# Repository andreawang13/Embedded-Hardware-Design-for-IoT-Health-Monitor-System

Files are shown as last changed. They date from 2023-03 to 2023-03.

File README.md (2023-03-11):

# PCB layout design
截屏2023-03-11 11 43 37
截屏2023-03-11 11 43 57
截屏2023-03-11 11 44 27

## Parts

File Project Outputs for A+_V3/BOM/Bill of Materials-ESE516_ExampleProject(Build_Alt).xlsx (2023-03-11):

Line # | Name | Description | Designator | Quantity | Manufacturer 1 | Manufacturer Part Number 1 | Manufacturer Lifecycle 1 | Supplier 1 | Supplier Part Number 1 | Supplier Unit Price 1 | Supplier Subtotal 1 | Actuator Color | Actuator Length | Actuator Travel | Actuator Type | Address1 | Address2 | Address3 | Address4 | Agency Approvals | Angle | Application_BuildNumber | Arrow Part Number | ApprovedBy | Arrow Price/Stock | Author | Automotive | Availability | Battery Chemistry | Battery Pack Voltage | Body Breadth | Body Depth | Body Length | Body/Shell Style | BOM Status Details | Brand | Brand/Series | Capacitance | BOM Status | Capacitance Value | Capacitor Type | Card Type | Case Code (Imperial) | Case Code (Metric) | Case/Package | Category | Category2 | Check_prices | CheckedBy | Circuit | Code_IPC | Color | CompanyName | Component Kind | ComponentKind | ComponentLink1Description | ComponentLink1URL | ComponentLink2Description | ComponentLink2URL
1 | PTS810SJK250SMTRLFS | Keypad Switch, 1 Switches, SPST, Momentary-tactile, 0.05A, 16VDC, 3.23N, Solder Terminal, Surface Mount-straight | B1, B3, B4 | 3 | Grayhill | 87FC3-201 | Volume Production | Digi-Key | GH7750-ND | 16.55 | 49.65 | White | 0.028inch | 0.1524mm | Pushbutton |  |  |  |  |  |  |  |  |  |  |  |  |  |  |  |  |  |  |  |  |  |  |  | Clear |  |  |  |  |  |  |  |  |  |  | SPST |  |  |  | Standard | 0
2 | CAP 0603 0.01UF 16V 10% X7R | Capacitor Surface Mount 0603 Footprint 0.01UF 16V 10% Tolerance Ceramic X7R | C1 | 1 | Yageo | CC0603KRX7R7BB103 | Volume Production | Digi-Key | 311-3369-1-ND | 0.1 | 0.1 |  |  |  |  |  |  |  |  |  |  |  |  |  |  |  |  |  |  |  |  |  |  |  |  |  |  |  | Clear |  |  |  |  |  |  |  |  |  |  |  |  |  |  | Standard | 0
3 | CAP 0603 0.1UF 16V 10% X7R | Capacitor Surface Mount 0603 Footprint 0.1UF 16V 10% Tolerance Ceramic X7R | C2, C6, C7, C15, C30 | 5 | Yageo | CC0603KRX7R7BB104 | Volume Production | Digi-Key | 311-1088-1-ND | 0.044 | 0.44 |  |  |  |  |  |  |  |  |  |  |  |  |  |  |  |  |  |  |  |  |  |  |  |  |  |  |  | Clear |  |  |  |  |  |  |  |  |  |  |  |  |  |  | Standard | 0
4 | CAP 0805 4.7UF 16V 10% X7R | Capacitor Surface Mount 0805 Footprint 4.7UF 16V 10% Tolerance Ceramic X7R | C3, C25, C26 | 3 | Yageo | CC0805KKX7R7BB475 | Volume Production | Digi-Key | 311-1883-1-ND | 0.39 | 1.17 |  |  |  |  |  |  |  |  |  |  |  |  |  |  |  |  |  |  |  |  |  |  |  |  |  |  |  | Clear |  |  |  |  |  |  |  |  |  |  |  |  |  |  | Standard | 0
5 | CAP 0603 47PF 50V 5% C0G | Capacitor Surface Mount 0603 Footprint 47PF 50V 5% Tolerance Ceramic C0G | C4, C5 | 2 | Yageo | 223886715479 | Volume Production | Quest | 223886715479 | 0.06 | 0.12 |  |  |  |  |  |  |  |  |  |  |  |  |  |  |  |  |  |  |  |  |  |  |  |  |  |  |  | Clear |  |  |  |  |  |  |  |  |  |  |  |  |  |  | Standard | 0
6 | CAP 0603 1UF 16V 10% X7R | Capacitor Surface Mount 0603 Footprint 1UF 16V 10% Tolerance Ceramic X7R | C8, C9, C12, C19, C20, C24 | 6 | Yageo | CC0603KRX7R7BB105 | Volume Production | Digi-Key | 311-1446-1-ND | 0.14 | 0.84 |  |  |  |  |  |  |  |  |  |  |  |  |  |  |  |  |  |  |  |  |  |  |  |  |  |  |  | Clear |  |  |  |  |  |  |  |  |  |  |  |  |  |  | Standard | 0
7 | CAP 0805 10UF 16V 20% X7R | Capacitor Surface Mount 0805 Footprint 10UF 16V 20% Tolerance Ceramic X7R | C10, C11, C18, C29, C31 | 5 | Yageo | CC1210KFX7R8BB106 | Unknown | Digi-Key | 13-CC1210KFX7R8BB106CT-ND | 0.53 | 2.65 |  |  |  |  |  |  |  |  |  |  |  |  |  |  |  |  |  |  |  |  |  |  |  |  |  |  |  | Clear |  |  |  |  |  |  |  |  |  |  |  |  |  |  | Standard | 0
8 | CAP 0603 18PF 50V 5% C0G | Capacitor Surface Mount 0603 Footprint 18PF 50V 5% Tolerance Ceramic C0G | C13, C14 | 2 | Yageo | CC0603JRNPO9BN180 | Volume Production | Digi-Key | 311-1061-1-ND | 0.1 | 0.2 |  |  |  |  |  |  |  |  |  |  |  |  |  |  |  |  |  |  |  |  |  |  |  |  |  |  |  | Clear |  |  |  |  |  |  |  |  |  |  |  |  |  |  | Standard | 0
9 | CC0805KPX7R9BB104 | CC0805 100 nF X7R 10.00% 50 V | C16, C17, C22, C27 | 4 | Yageo | CC0805KPX7R9BB104 | Volume Production | Digi-Key | 13-CC0805KPX7R9BB104CT-ND | 0.1 | 0.4 |  |  |  |  |  |  |  |  |  |  |  |  |  |  |  | No |  |  |  |  |  |  |  |  |  |  | 100 nF | Clear |  |  |  |  |  |  | Cap |  |  |  |  |  |  |  | Standard | 0 |  |  | Datasheet | http://www.yageo.com/documents/recent/UPY-GPHC_Y5V_6.3V-to-50V_8.pdf
10 | CAP 1206 10UF 50V 10% X5R | Capacitor Surface Mount 1206 Footprint 10UF 25V 10% Tolerance Ceramic X5R | C21 | 1 | Yageo | CC1210KFX7R8BB106 | Unknown | Digi-Key | 13-CC1210KFX7R8BB106CT-ND | 0.53 | 0.53 |  |  |  |  |  |  |  |  |  |  |  |  |  |  |  |  |  |  |  |  |  |  |  |  |  |  |  | Clear |  | Ceramic |  |  |  | 1206 |  |  |  |  |  |  |  |  | Standard | 0
11 | CC0805MKX7R8BB475 | CAP CER 4.7UF 25V X7R 0805 | C23 | 1 | Yageo | CC0805MKX7R8BB475 | Volume Production | Digi-Key | 311-3509-1-ND | 0.39 | 0.39 |  |  |  |  |  |  |  |  |  |  |  |  |  |  |  | No |  |  |  |  |  |  |  |  |  |  | 4.7 uF | Clear |  |  |  |  |  |  | Cap |  |  |  |  |  |  |  | Standard | 0 |  |  | Datasheet | http://www.yageo.com/documents/recent/UPY-GPHC_Y5V_6.3V-to-50V_8.pdf
12 | CAP 1206 22UF 10V 10% X7R | Capacitor Surface Mount 1206 Footprint 22UF 10V 10% Tolerance Ceramic X7R | C28 | 1 | Yageo | CC1210MKX7R7BB226 | Volume Production | Digi-Key | 311-2057-1-ND | 0.68 | 0.68 |  |  |  |  |  |  |  |  |  |  |  |  |  |  |  |  |  |  |  |  |  |  |  |  |  |  |  | Clear |  | Ceramic |  |  |  | 1206 |  |  |  |  |  |  |  |  | Standard | 0
13 | LSM0805412V | Single Color LED, RED, 0805 | D1, D3, D11 | 3 | Visual Communications | LSM0805412V | Volume Production | Digi-Key | 28-LSM0805412VDKR-ND | 0.47 | 1.41 |  |  |  |  |  |  |  |  |  |  |  |  |  |  |  |  |  |  |  |  |  |  |  |  |  |  |  | Clear |  |  |  |  |  |  |  |  |  |  |  |  |  |  | Standard | 0
14 | PRTR5V0U2X,215 | Ultra Low Capacitance Double Rail-to-Rail ESD Protection Diode, 5.5 V, 1 pF, -40 to 85 degC, 4-Pin SOT143B, RoHS, Tape and Reel | D2 | 1 | Nexperia | PRTR5V0U2X,215 | Volume Production | Digi-Key | 1727-3884-1-ND | 0.51 | 0.51 |  |  |  |  |  |  |  |  |  |  |  |  |  |  |  |  |  |  |  |  |  |  |  |  |  |  |  | Clear | 16pF |  |  |  |  |  |  |  |  |  |  |  |  |  | Standard | 0
15 | LSM0805452V | Single Color LED, Green, 0805 | D4, D8, D9, D10 | 4 | Visual Communications | LSM0805452V | Volume Production | Digi-Key | 28-LSM0805452VCT-ND | 0.41 | 1.64 |  |  |  |  |  |  |  |  |  |  |  |  |  |  |  |  |  |  |  |  |  |  |  |  |  |  |  | Clear |  |  |  |  |  |  |  |  |  |  |  |  |  |  | Standard | 0
16 | BLM21PG221SN1D | Chip Ferrite Bead, 0805, 220Ω @ 100MHz, 0.045Ω, 25%, 2A | FB1 | 1 | Murata | BLM21PG221SN1D | Unknown | Digi-Key | 490-1054-1-ND | 0.12 | 0.12 |  |  |  |  |  |  |  |  |  |  |  |  |  |  |  |  |  |  |  |  |  |  |  |  |  |  |  | Clear |  |  |  | 0805 | 2012 | 0805 |  |  |  |  |  |  |  |  | Standard | 0
17 | LTC1503CS8-1.8 | Integrated Circuit | IC1 | 1 | Analog Devices / Linear Technology | LTC1503CS8-1.8#PBF | Volume Production | Digi-Key | LTC1503CS8-1.8#PBF-ND | 6.07 | 6.07 |  |  |  |  |  |  |  |  |  |  |  |  |  |  |  |  |  |  |  |  |  |  |  |  |  |  |  | Clear |  |  |  |  |  |  |  |  |  |  |  |  |  |  | Standard | 0
18 | 10103592-0001LF | Conn Micro USB 2.0 Type B RCP 5 POS 0.65mm Solder RA SMD 5 Terminal 1 Port T/R | J1 | 1 | Amphenol Communications Solutions | 10103592-0001LF | Unknown | Digi-Key | 609-4048-1-ND | 0.8 | 0.8 |  |  |  |  |  |  |  |  |  |  |  |  |  |  |  |  |  |  |  |  |  |  |  |  |  |  |  | Clear |  |  |  |  |  |  |  |  |  |  |  |  |  |  | Standard | 0
19 | PAM2401 | Conv DC-DC 0.9V to 4.75V Synchronous Step Up Single-Out 2.5V to 5V 12-Pin UDFN EP T/R | J2 | 1 | Diodes | PAM2401SCADJ | Volume Production | Digi-Key | PAM2401SCADJDITR-ND | 0.45 | 1125 |  |  |  |  |  |  |  |  |  |  |  |  |  |  |  |  | In Stock |  |  |  |  |  |  |  |  |  |  | Clear |  |  |  |  |  |  |  |  | https://www.snapeda.com/parts/PAM2401/Zetex/view-part/?ref=eda |  |  |  |  |  | Standard | 0
20 | 2.2uH | IND 2.2uH 0.22A 280mâ„| | L1 | 1 | Murata | LQM21PN2R2NGCD | Volume Production | Digi-Key | 490-7781-6-ND | 0.23 | 0.23 |  |  |  |  |  |  |  |  |  |  |  |  |  |  |  |  | In Stock |  |  |  |  |  |  |  |  |  |  | Clear |  |  |  |  |  |  |  |  | https://www.snapeda.com/parts/ASMCI-0805-2R2M-T/Abracon/view-part/?ref=eda |  |  |  |  |  | Standard | 0
21 | 640456-3 | CONN HEADER VERT 3POS 2.54MM | P1, P2 | 2 | TE Connectivity | 640456-2 | Volume Production | Digi-Key | A1921-ND | 0.14 | 0.28 |  |  |  |  |  |  |  |  | CSA,UL | Straight |  |  |  |  |  |  |  |  |  |  |  |  |  |  |  | MTA-100Series |  | Clear |  |  |  |  |  |  |  |  |  |  |  |  | White |  | Standard | 0
22 | BSS138 | N-CH MOSFET 50V 0.34A SOT-23-3L | Q1, Q2 | 2 | Diodes | BSS138W-7-F | Volume Production | Digi-Key | BSS138W-FDIDKR-ND | 0.31 | 0.62 |  |  |  |  |  |  |  |  |  |  |  |  |  |  |  |  | In Stock |  |  |  |  |  |  |  |  |  |  | Clear |  |  |  |  |  |  |  |  | https://www.snapeda.com/parts/BSS138/Diodes+Inc./view-part/?ref=eda |  |  |  |  |  | Standard | 0
23 | RES 0603 27 1% | Resistor Surface Mount, 27 Ohms, 0603 Footprint, 1% Tolerance 0.1W | R1, R2, R8, R9, R10 | 5 | Stackpole Electronics | RMCF0402FT27R0 | Volume Production | Digi-Key | RMCF0402FT27R0CT-ND | 0.014 | 0.14 |  |  |  |  |  |  |  |  |  |  |  |  |  |  |  |  |  |  |  |  |  |  |  |  |  |  |  | Clear |  |  |  |  |  |  |  |  |  |  |  |  |  |  | Standard | 0
24 | RES 0603 1K 1% | Resistor Surface Mount, 1K Ohms, 0603 Footprint, 1% Tolerance 0.1W | R3, R5, R6, R7, R18, R19, R37, R38 | 8 | Yageo | RC0603FR-071KL | Unknown | Digi-Key | 311-1.00KHRDKR-ND | 0.019 | 0.19 |  |  |  |  |  |  |  |  |  |  |  |  |  |  |  |  |  |  |  |  |  |  |  |  |  |  |  | Clear |  |  |  |  |  |  |  |  |  |  |  |  |  |  | Standard | 0
25 | RES 0805 0 5% | Resistor Surface Mount, 0 Ohms, 0805 Footprint, 5% Tolerance 0.125W | R4, R16, R23, R24, R27, R35, R39, R41, R42, R45, R47, R48, R49, R50, R51, R? | 16 | Rohm | KTR10EZPJ205 | Volume Production | Digi-Key | RHM2.0MBCT-ND | 0.143 | 2.29 |  |  |  |  |  |  |  |  |  |  |  |  |  |  |  |  |  |  |  |  |  |  |  |  |  |  |  | Clear |  |  |  |  |  |  |  |  |  |  |  |  |  |  | Standard | 0
26 | RES 0603 10K 1% | Resistor Surface Mount, 10K Ohms, 0603 Footprint, 1% Tolerance 0.1W | R11, R13, R14, R15, R30, R31, R32, R52, R53 | 9 | Stackpole Electronics | RMCF0603FT10K0 | Volume Production | Digi-Key | RMCF0603FT10K0DKR-ND | 0.016 | 0.16 |  |  |  |  |  |  |  |  |  |  |  |  |  |  |  |  |  |  |  |  |  |  |  |  |  |  |  | Clear |  |  |  |  |  |  |  |  |  |  |  |  |  |  | Standard | 0
27 | RES 0603 100 1% | Resistor Surface Mount, 100 Ohms, 0603 Footprint, 1% Tolerance 0.1W | R12 | 1 | Stackpole Electronics | RMCF0402FT100R | Volume Production | Digi-Key | RMCF0402FT100RCT-ND | 0.1 | 0.1 |  |  |  |  |  |  |  |  |  |  |  |  |  |  |  |  |  |  |  |  |  |  |  |  |  |  |  | Clear |  |  |  |  |  |  |  |  |  |  |  |  |  |  | Standard | 0
28 | RES 0402 4.7K 1% | Resistor Surface Mount, 4.7K Ohms, 0402 Footprint, 1% Tolerance 0.063W | R17, R22, R28, R29, R33, R34, R40 | 7 | Stackpole Electronics | RMCF0402FT4K70 | Volume Production | Digi-Key | RMCF0402FT4K70DKR-ND | 0.014 | 0.14 |  |  |  |  |  |  |  |  |  |  |  |  |  |  |  |  |  |  |  |  |  |  |  |  |  |  |  | Clear |  |  |  |  |  |  |  |  |  |  |  |  |  |  | Standard | 0
29 | RES 0603 1.13K 1% | Resistor Surface Mount, 1.13K Ohms, 0603 Footprint, 1% Tolerance 0.1W | R20, R21 | 2 | Stackpole Electronics | RMCF0402FT1K13 | Volume Production | Digi-Key | RMCF0402FT1K13CT-ND | 0.014 | 0.14 |  |  |  |  |  |  |  |  |  |  |  |  |  |  |  |  |  |  |  |  |  |  |  |  |  |  |  | Clear |  |  |  |  |  |  |  |  |  |  |  |  |  |  | Standard | 0
30 | RES 0402 750K 5% | Resistor Surface Mount, 750K Ohms, 0402 Footprint, 5% Tolerance 0.063W | R25 | 1 | Stackpole Electronics | RMCF0402FT750K | Volume Production | Digi-Key | RMCF0402FT750KCT-ND | 0.1 | 0.1 |  |  |  |  |  |  |  |  |  |  |  |  |  |  |  |  |  |  |  |  |  |  |  |  |  |  |  | Clear |  |  |  |  |  |  |  |  |  |  |  |  |  |  | Standard | 0
31 | RES 0603 100K 5% | Resistor Surface Mount, 100K Ohms, 0603 Footprint, 5% Tolerance 0.1W | R26, R36 | 2 | Stackpole Electronics | RMCF0603JG100K | Volume Production | Digi-Key | RMCF0603JG100KCT-ND | 0.014 | 0.14 |  |  |  |  |  |  |  |  |  |  |  |  |  |  |  |  |  |  |  |  |  |  |  |  |  |  |  | Clear |  |  |  |  |  |  |  |  |  |  |  |  |  |  | Standard | 0
32 | 104031-0811 | Micro SD Card, RA, -25 to 85 degC, 8-Pin SMD, RoHS, Tape and Reel | SD1 | 1 | Molex | 1040310811 | Unknown | Digi-Key | WM6357DKR-ND | 2.24 | 2.24 |  |  |  |  |  |  |  |  |  |  |  |  |  |  |  |  |  |  |  |  |  |  |  |  | Molex |  |  | Clear |  |  | microSD |  |  |  |  |  |  |  |  |  |  |  | Standard | 0
33 | FT234XD-R | IC USB SERIAL BASIC UART 12DFN | U1 | 1 | FTDI | FT234XD-R | Volume Production | Digi-Key | 768-1178-1-ND | 2.26 | 2.26 |  |  |  |  |  |  |  |  |  |  |  |  |  |  |  |  |  |  |  |  |  |  |  |  |  |  |  | Clear |  |  |  |  |  | DFN |  |  |  |  |  |  |  |  | Standard | 0
34 | MCP1824T-3302E/OT | 300 mA, Low Voltage, Low Quiescent Current LDO Regulator, 5-Pin SOT-23, Extended Temperature, Tape and Reel | U2 | 1 | Microchip | MCP1824T-3302E/OT | Volume Production | Digi-Key | MCP1824T-3302E/OTCT-ND | 0.59 | 0.59 |  |  |  |  |  |  |  |  |  |  |  |  |  |  |  |  |  |  |  |  |  |  |  |  |  |  |  | Clear |  |  |  |  |  |  |  |  |  |  |  | SOT23-5 |  |  | Standard | 0
35 | 20021111-00010T4LF | Board Connector, 10 Contact(s), 2 Row(s), Male, Straight, 0.05 inch Pitch, Solder Terminal, Locking, Black Insulator, Receptacle | U3 | 1 | Amphenol ICC / FCI | 20021111-00010T4LF | Unknown | Mouser | 649-221111-00010T4LF | 0.79 | 0.79 |  |  |  |  |  |  |  |  |  |  |  |  |  |  |  |  |  |  |  | 0.135inch | 0.098inch | 0.25inch | RECEPTACLE |  |  |  |  | Clear |  |  |  |  |  |  |  |  |  |  |  |  |  |  | Standard | 0
36 | ATSAMW25H18-MR210PB | 2.7 - 4.2 V 65 Mbps 17 dbm 256 kB Flash 32 kB SRAM 802.11 b/g/n Smart Module | U4 | 1 | Microchip | ATSAMW25H18-MR210PB1954 | Volume Production | microchipDIRECT | ATSAMW25H18-MR210PB1954 | 15.15 | 15.15 |  |  |  |  |  |  |  |  |  |  |  |  |  |  |  |  |  |  |  |  |  |  |  |  |  |  |  | Clear |  |  |  |  |  |  |  |  |  |  |  |  |  |  | Standard | 0
37 | BQ24075RGTR | IC LI-ION CHARGE MGMT 16-QFN | U6 | 1 | Texas Instruments | BQ24075RGTR | Volume Production | Digi-Key | 296-38874-1-ND | 2.53 | 2.53 |  |  |  |  |  |  |  |  |  |  |  |  |  |  |  |  |  | LITHIUM-ION | 4.2V |  |  |  |  |  |  |  |  | Clear |  |  |  |  |  | VQFN |  |  |  |  |  |  |  |  | Standard | 0
38 | MAX30101EFD+ | Oximeter/Heart Rate Sensor IÂ²C Output | U7 | 1 | Maxim | MAX30101EFD+ | Volume Production | One Stop Electro | 55433695 | 1.65 | 1.65 |  |  |  |  |  |  |  |  |  |  |  |  |  |  |  |  | Unavailable |  |  |  |  |  |  |  |  |  |  | Clear |  |  |  |  |  |  |  |  |  |  |  |  |  |  | Standard | 0
39 | BME680 | Gas, Humidity, Pressure, Temperature Sensor IÂ²C, SPI Output | U9 | 1 | Bosch Sensortec | BME680 | Unknown | LKR | 9004993 | 8.69 | 8.69 |  |  |  |  |  |  |  |  |  |  |  |  |  |  |  |  | In Stock |  |  |  |  |  |  |  |  |  |  | Clear |  |  |  |  |  |  |  |  | https://www.snapeda.com/parts/BME680/Bosch+Sensortec/view-part/?ref=eda |  |  |  |  |  | Standard | 0
40 | ABS07-32.768KHZ-T | Crystal 32.768kHz ±20ppm (Tol) 12.5pF FUND 70kΩ 2-Pin CSMD T/R | X1 | 1 | Abracon | ABS07-32.768KHZ-T | Volume Production | Digi-Key | 535-9542-1-ND | 0.72 | 0.72 |  |  |  |  |  |  |  |  |  |  |  |  |  |  |  |  |  |  |  |  |  |  |  |  |  |  |  | Clear |  |  |  |  |  | CSMD |  |  |  |  |  |  |  |  | Standard | 0
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

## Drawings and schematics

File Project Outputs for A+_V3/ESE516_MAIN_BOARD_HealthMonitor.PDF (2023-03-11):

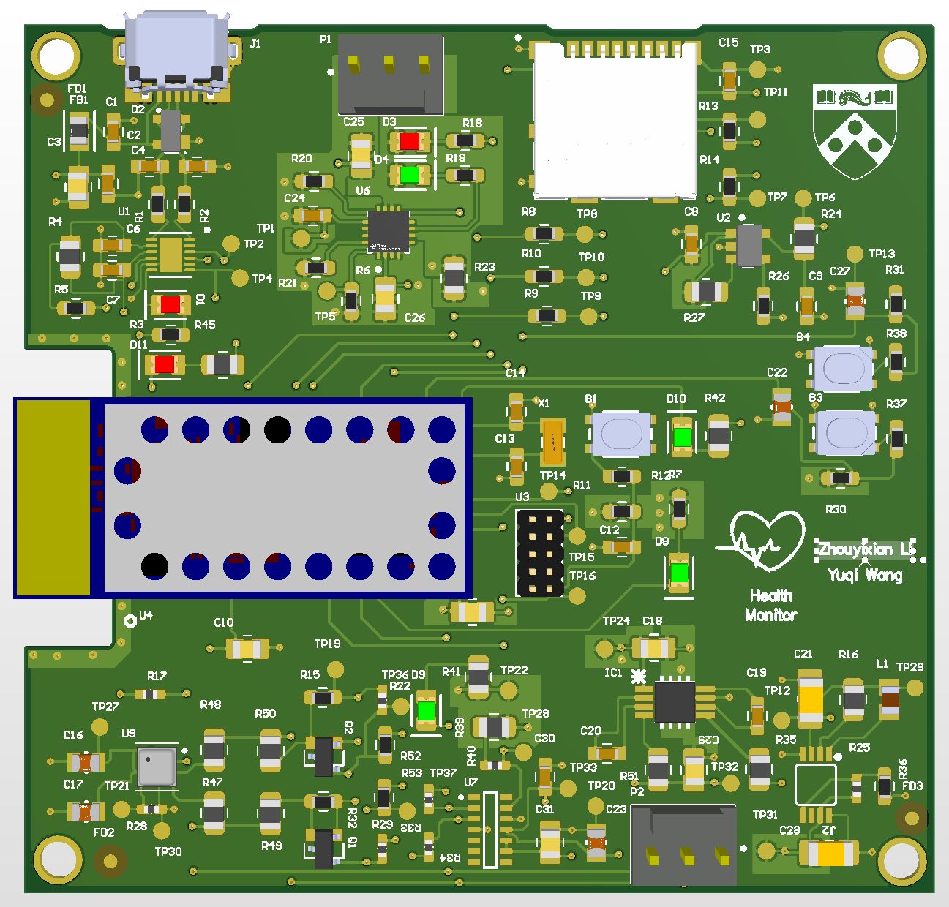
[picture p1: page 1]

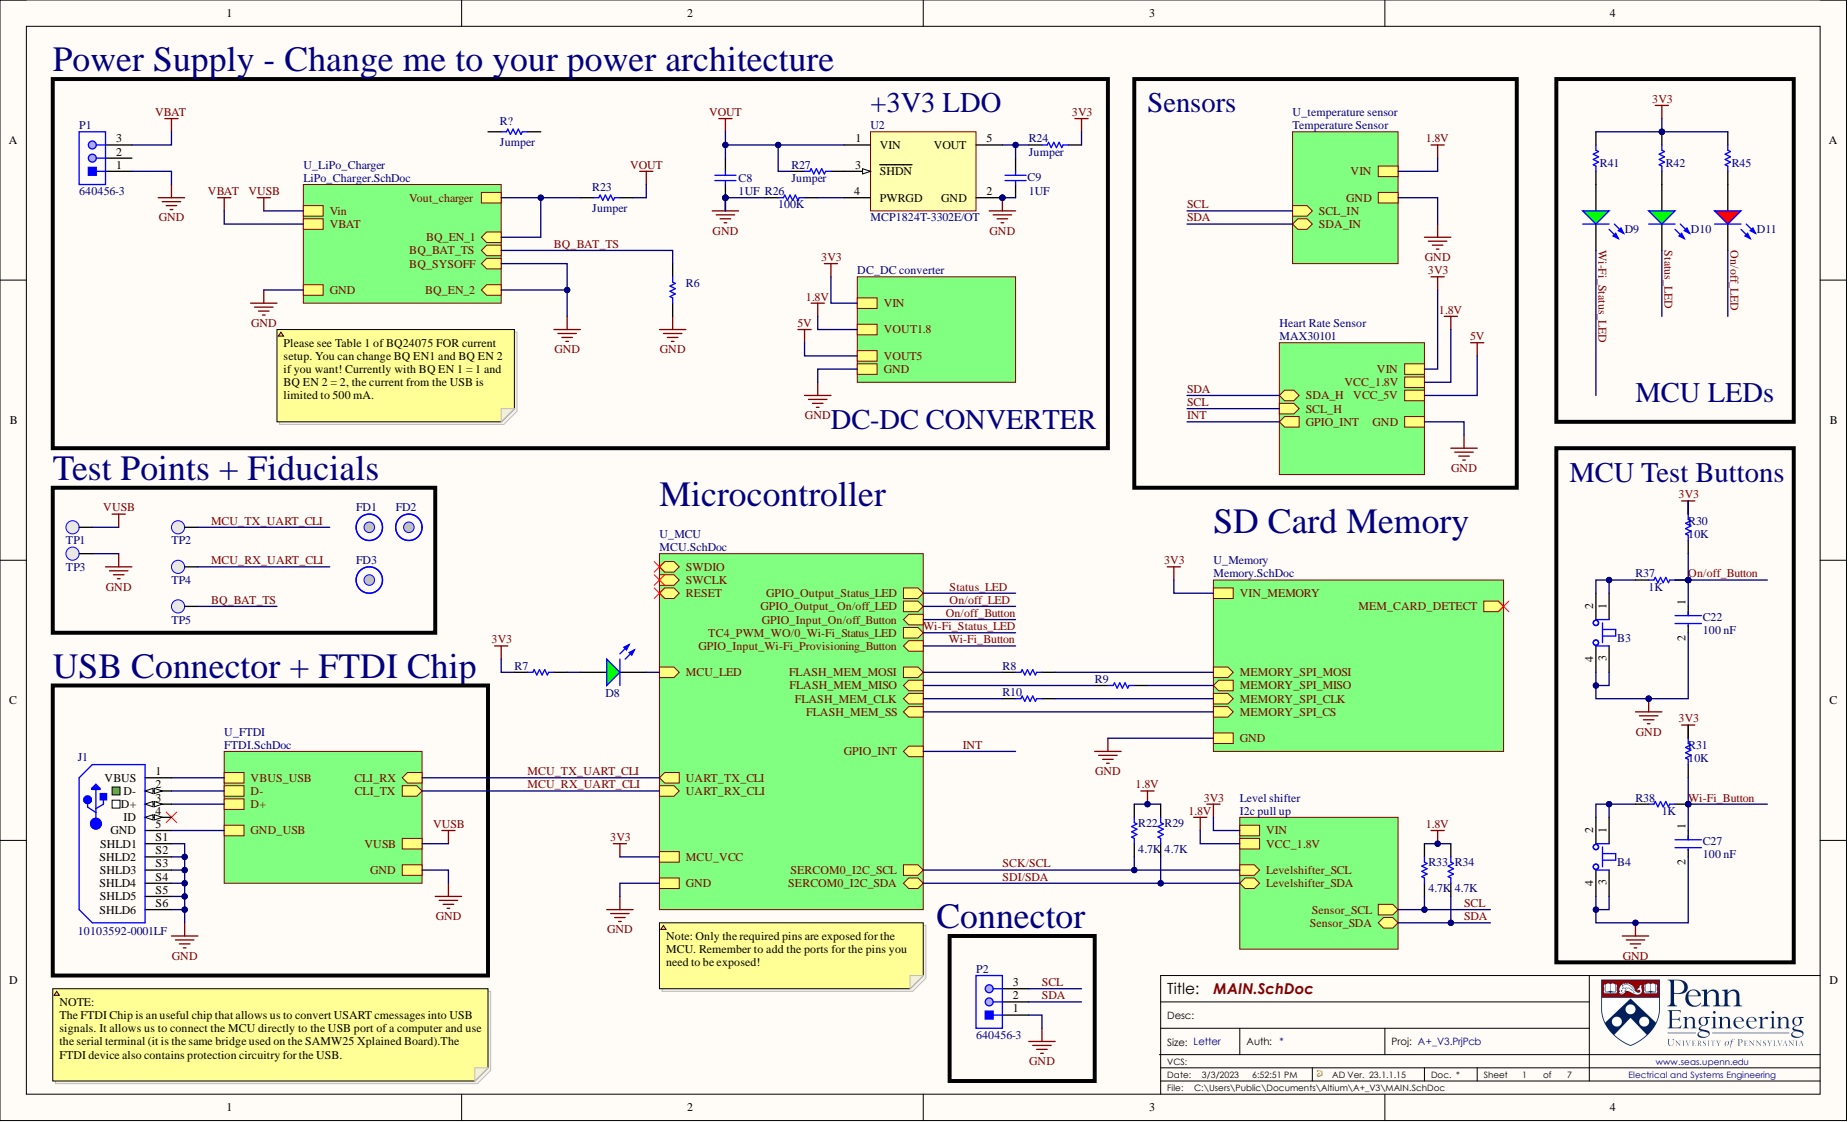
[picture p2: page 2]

Power Supply - Change me to your power architecture

USB Connector + FTDI Chip

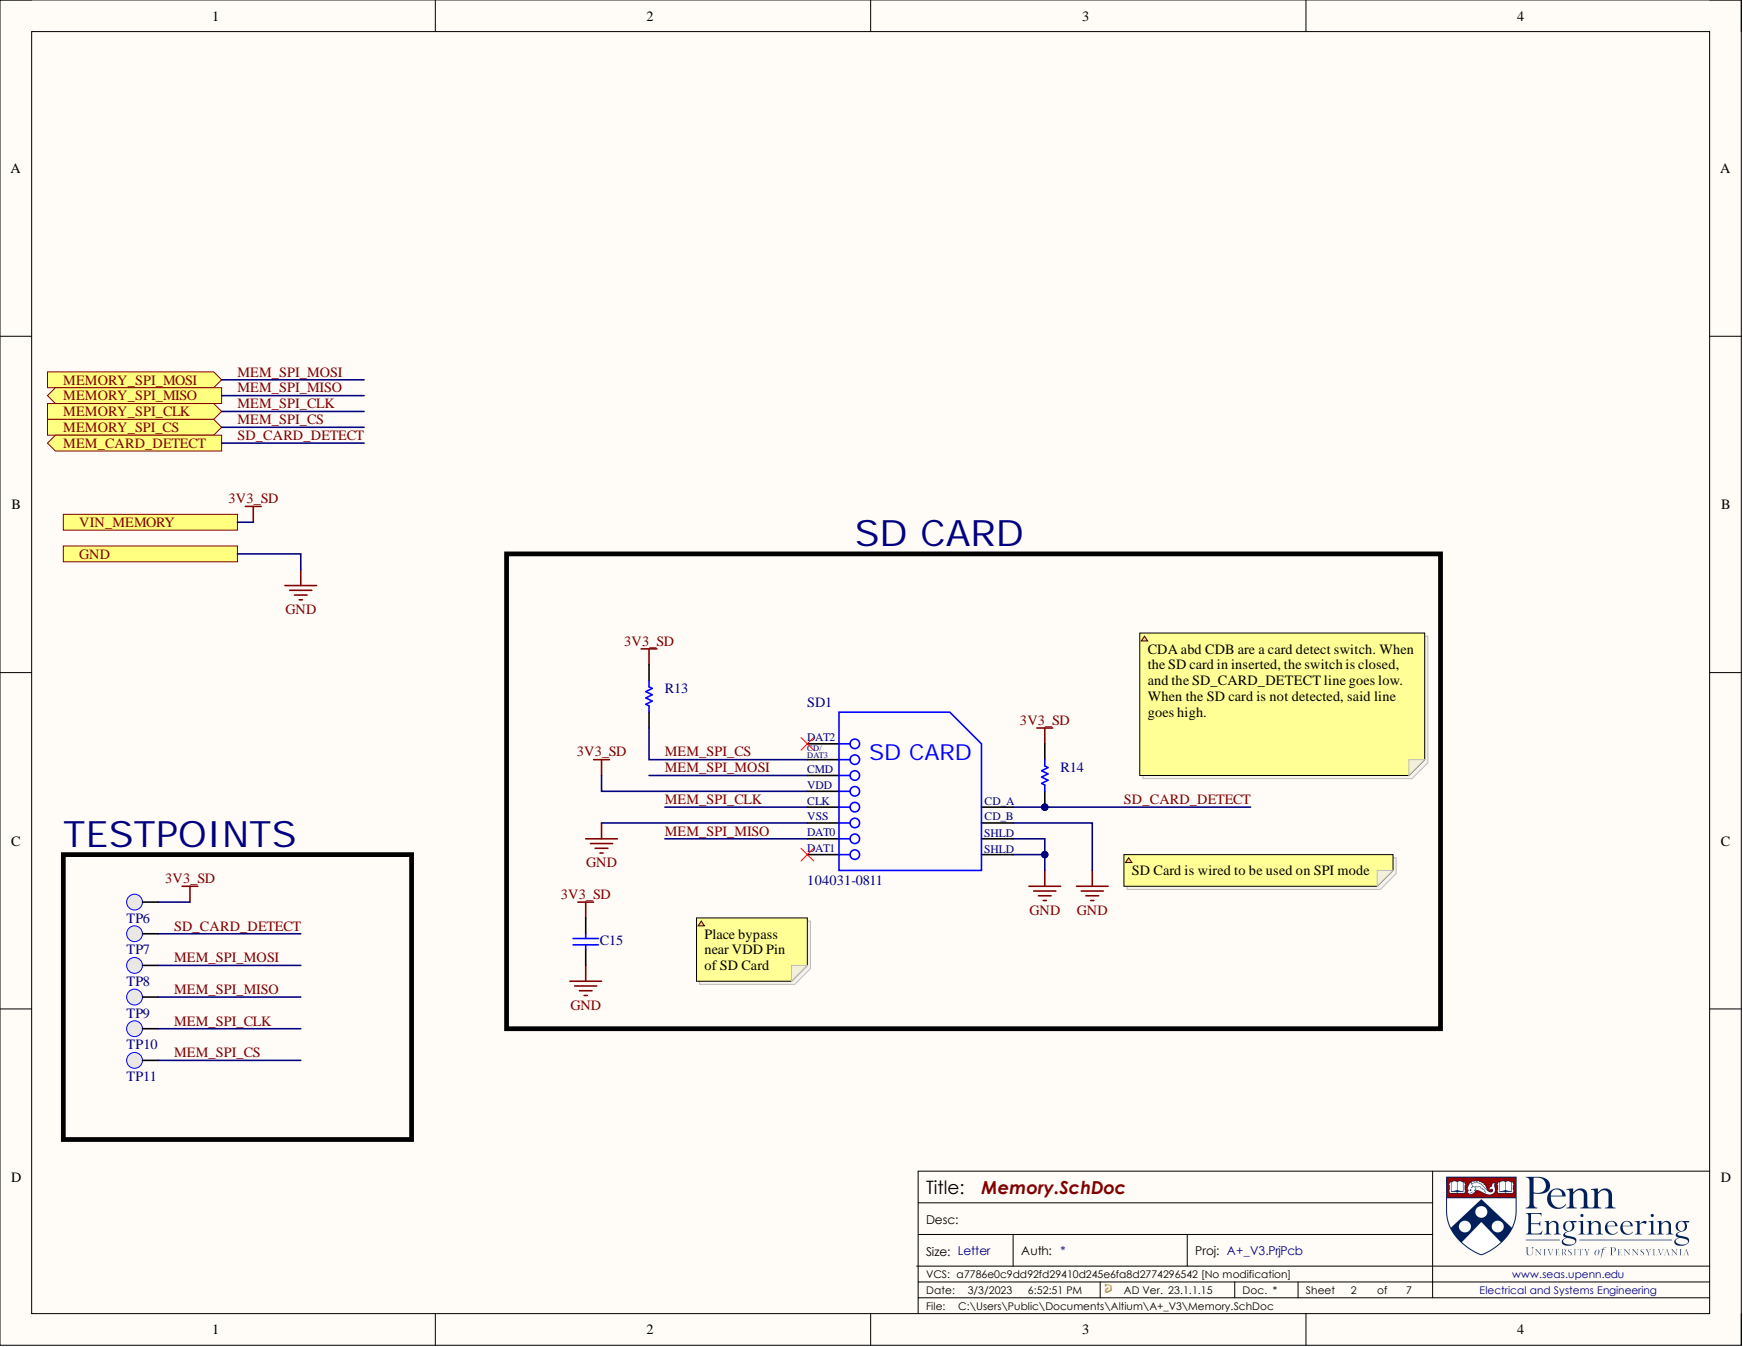
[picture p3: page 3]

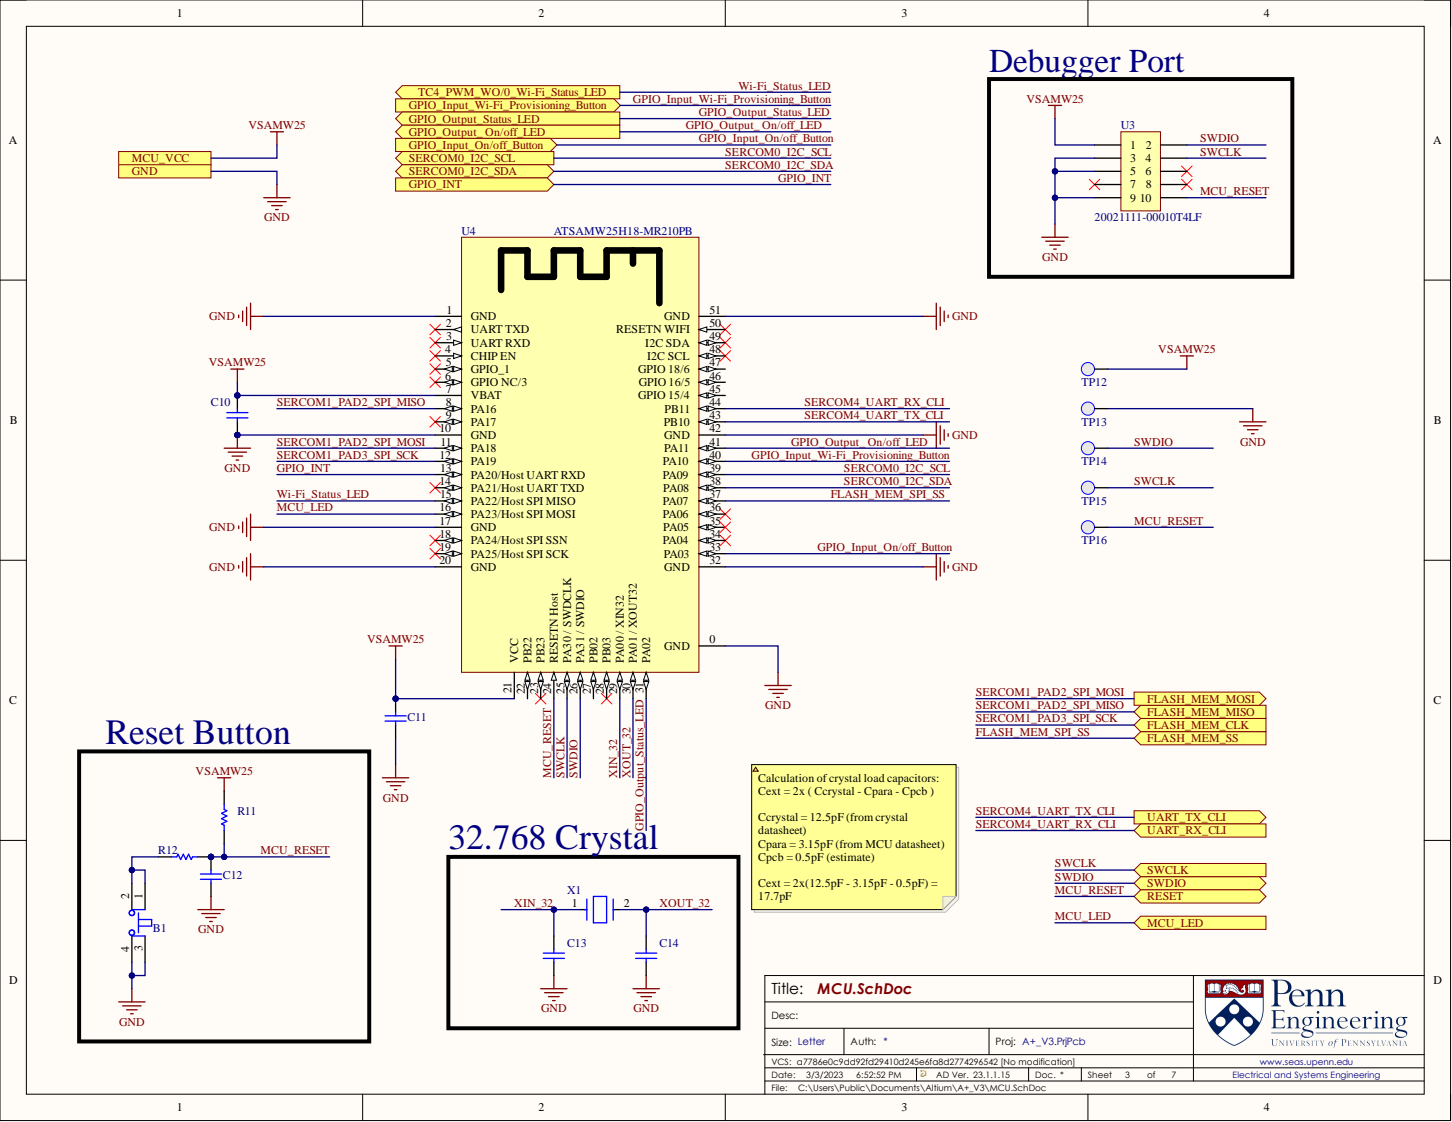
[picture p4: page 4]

Calculation of crystal load capacitors:
Cext = 2x ( Ccrystal - Cpara - Cpcb )

Ccrystal = 12.5pF (from crystal
datasheet)
Cpara = 3.15pF (from MCU datasheet)
Cpcb = 0.5pF (estimate)

www.seas.upenn.edu

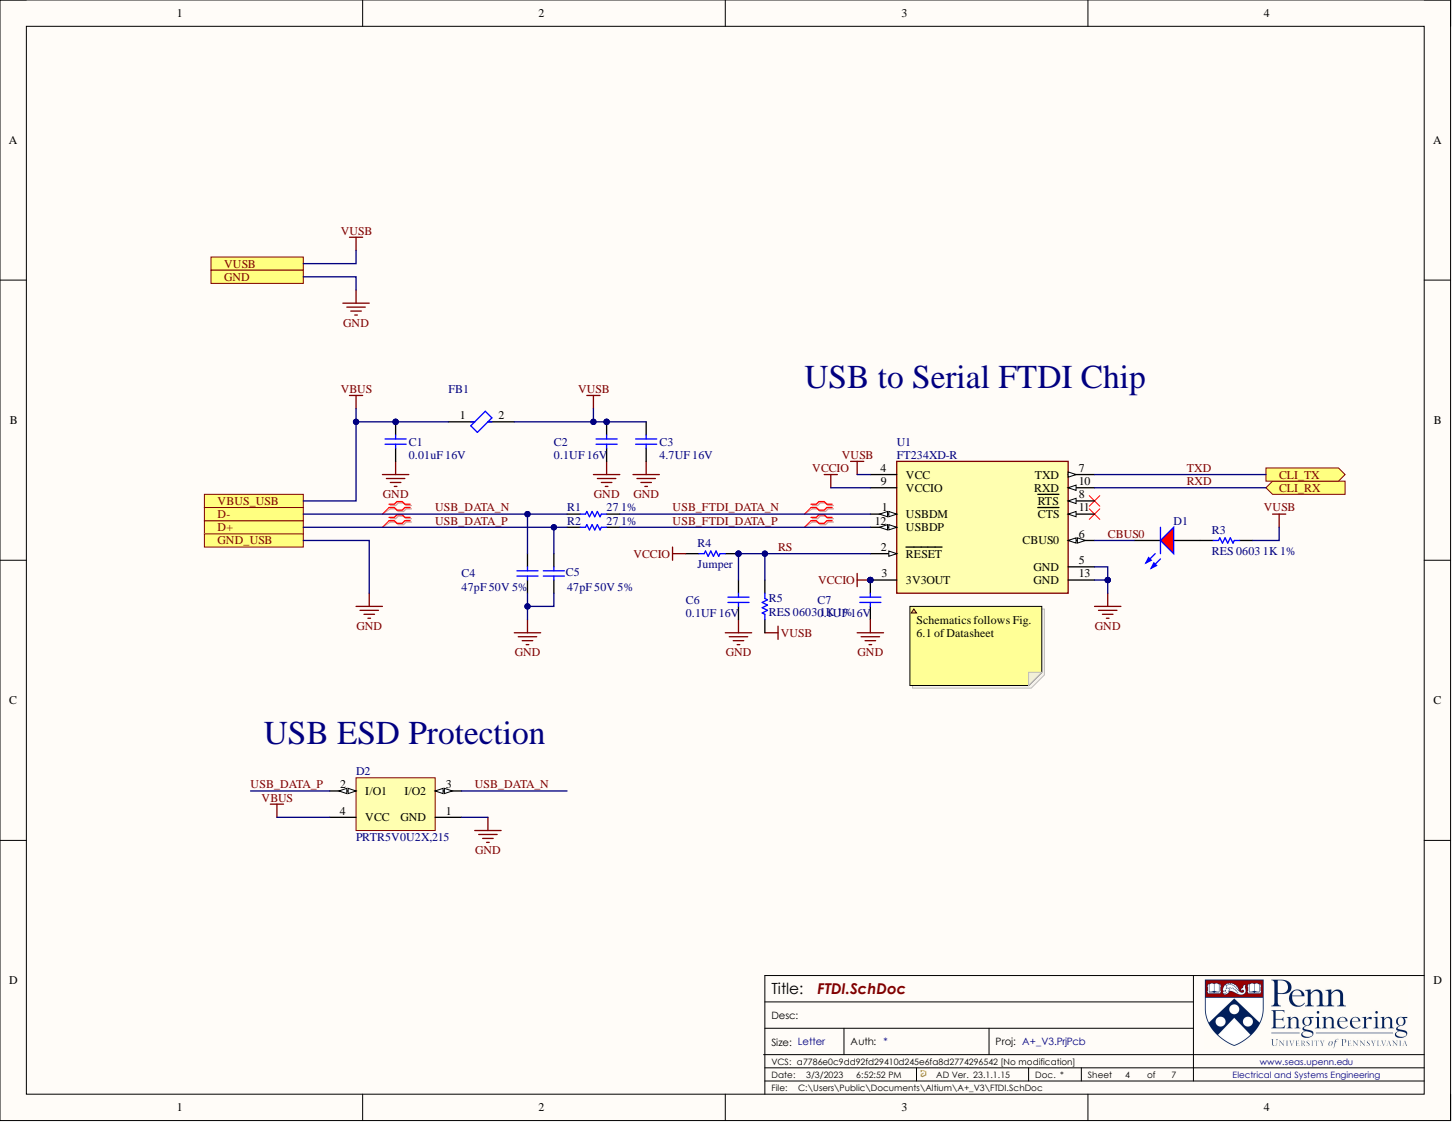
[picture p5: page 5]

www.seas.upenn.edu

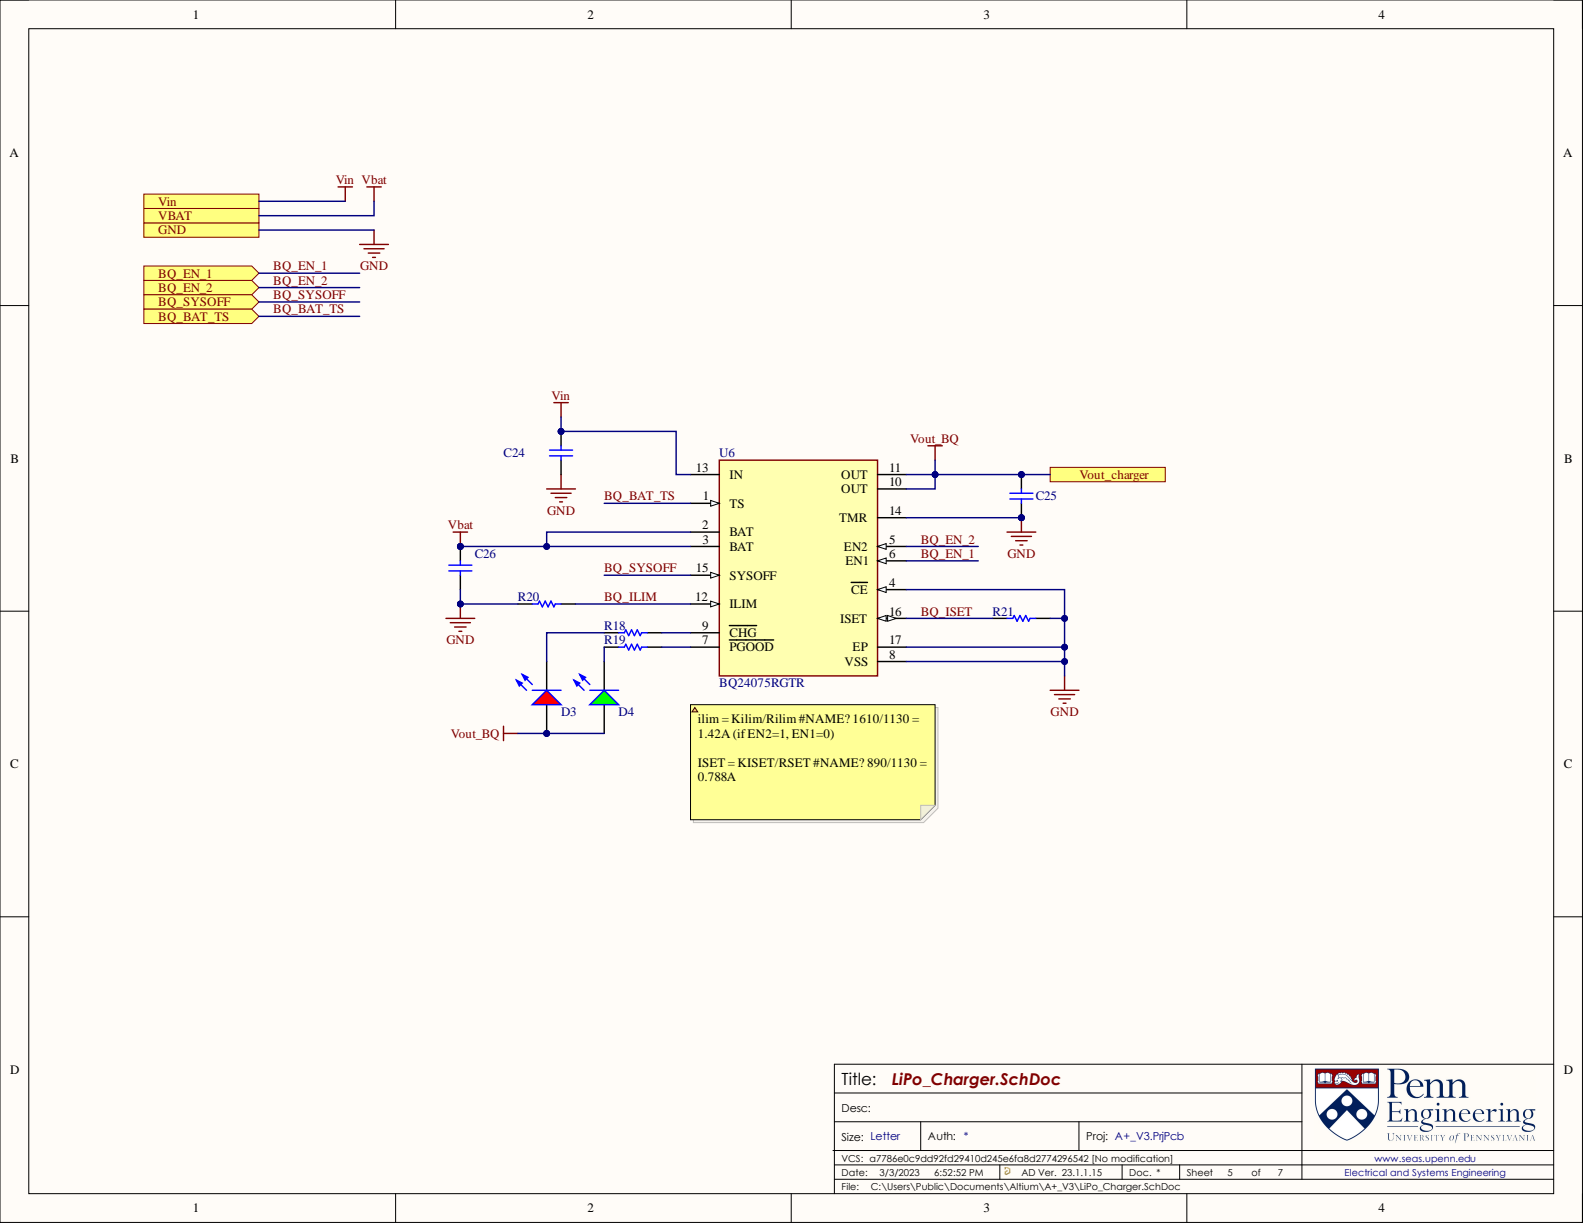
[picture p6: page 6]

ISET = KISET/RSET #NAME? 890/1130 =

www.seas.upenn.edu

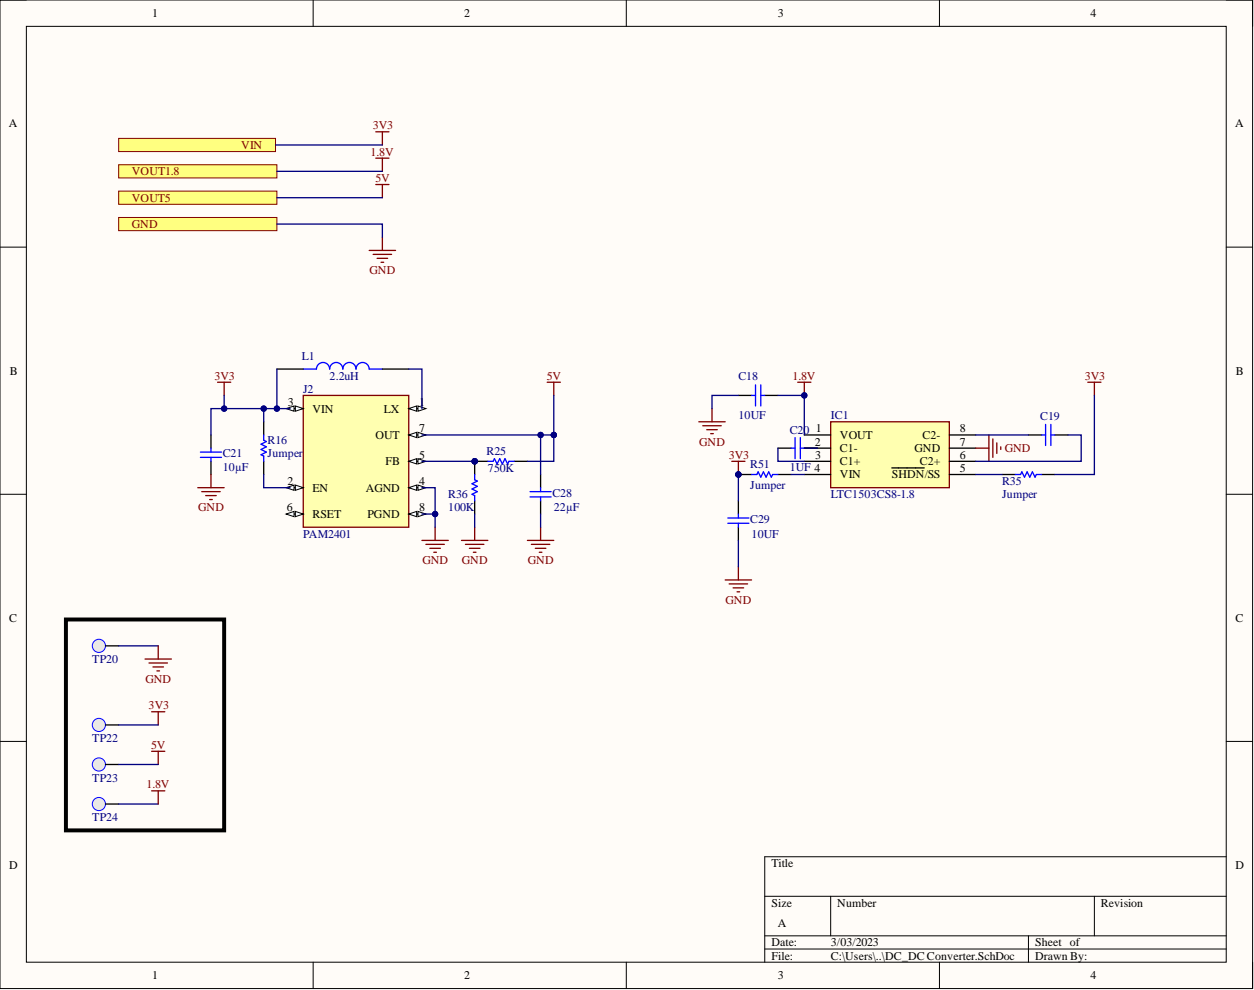
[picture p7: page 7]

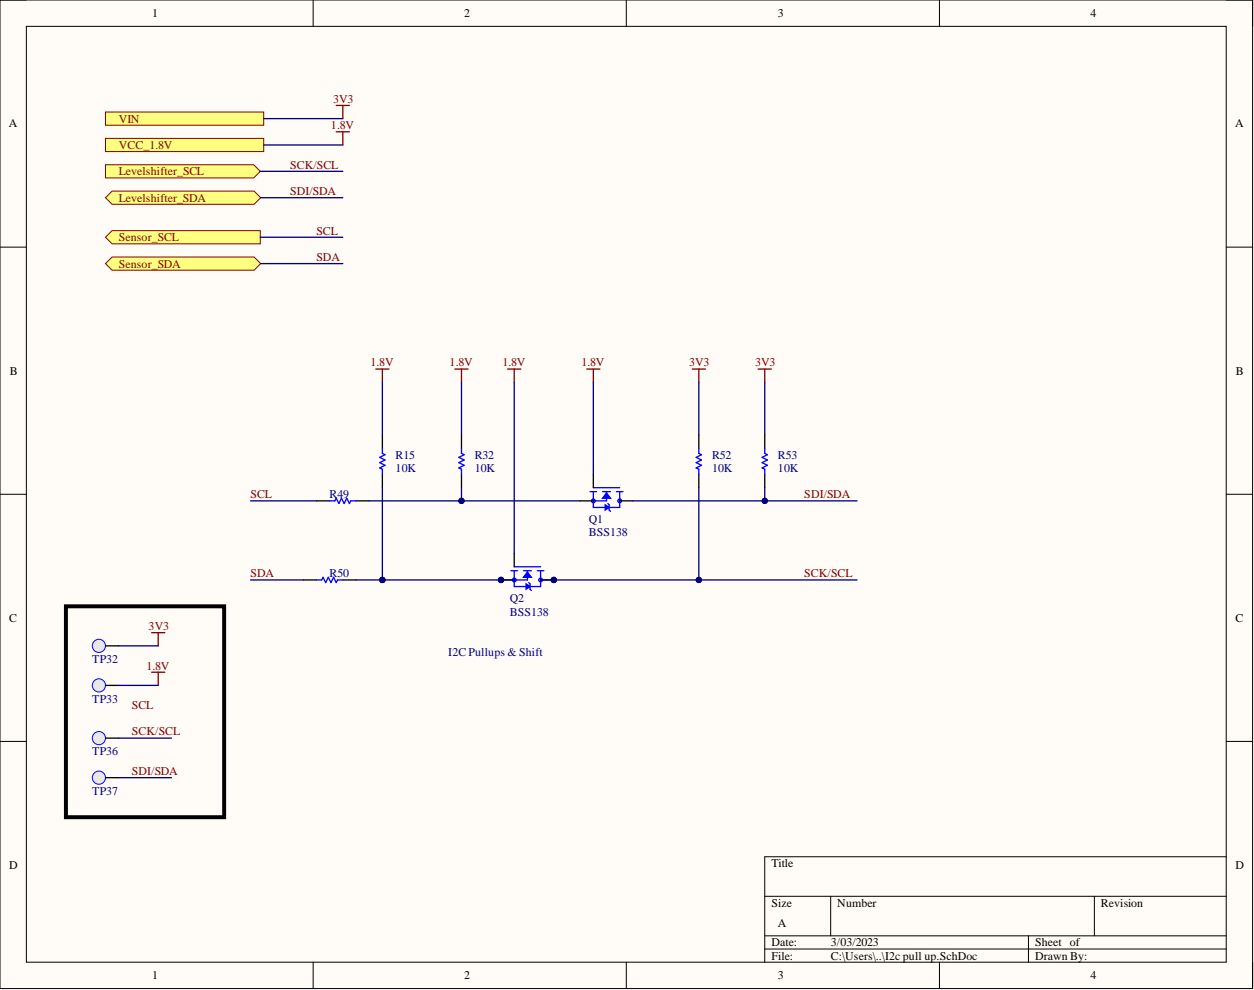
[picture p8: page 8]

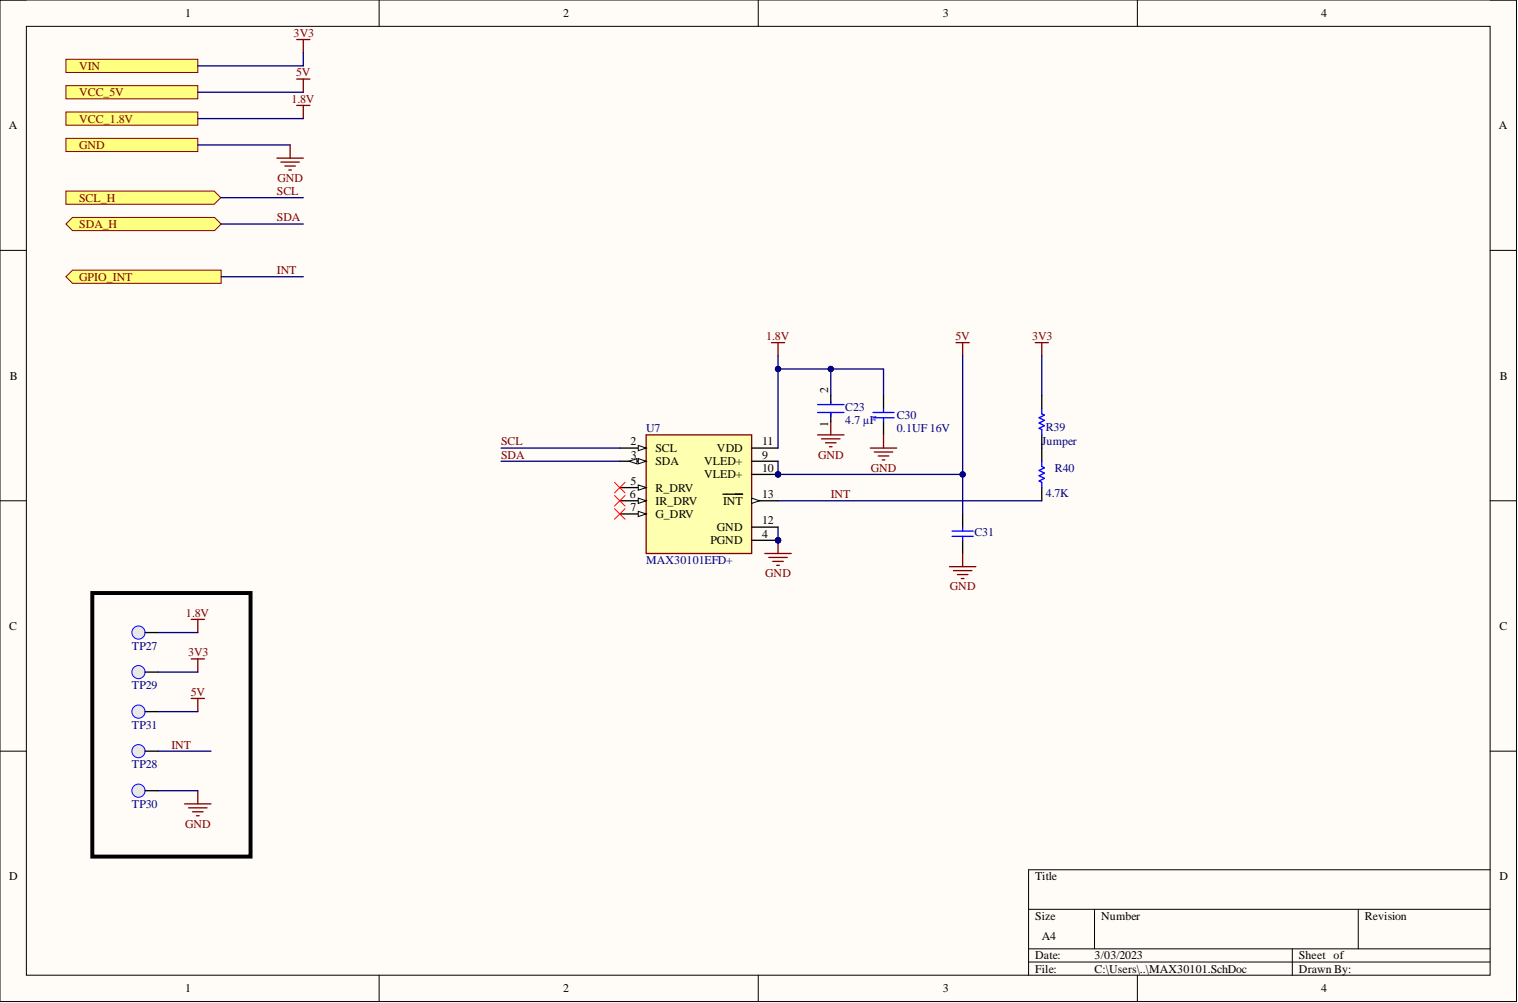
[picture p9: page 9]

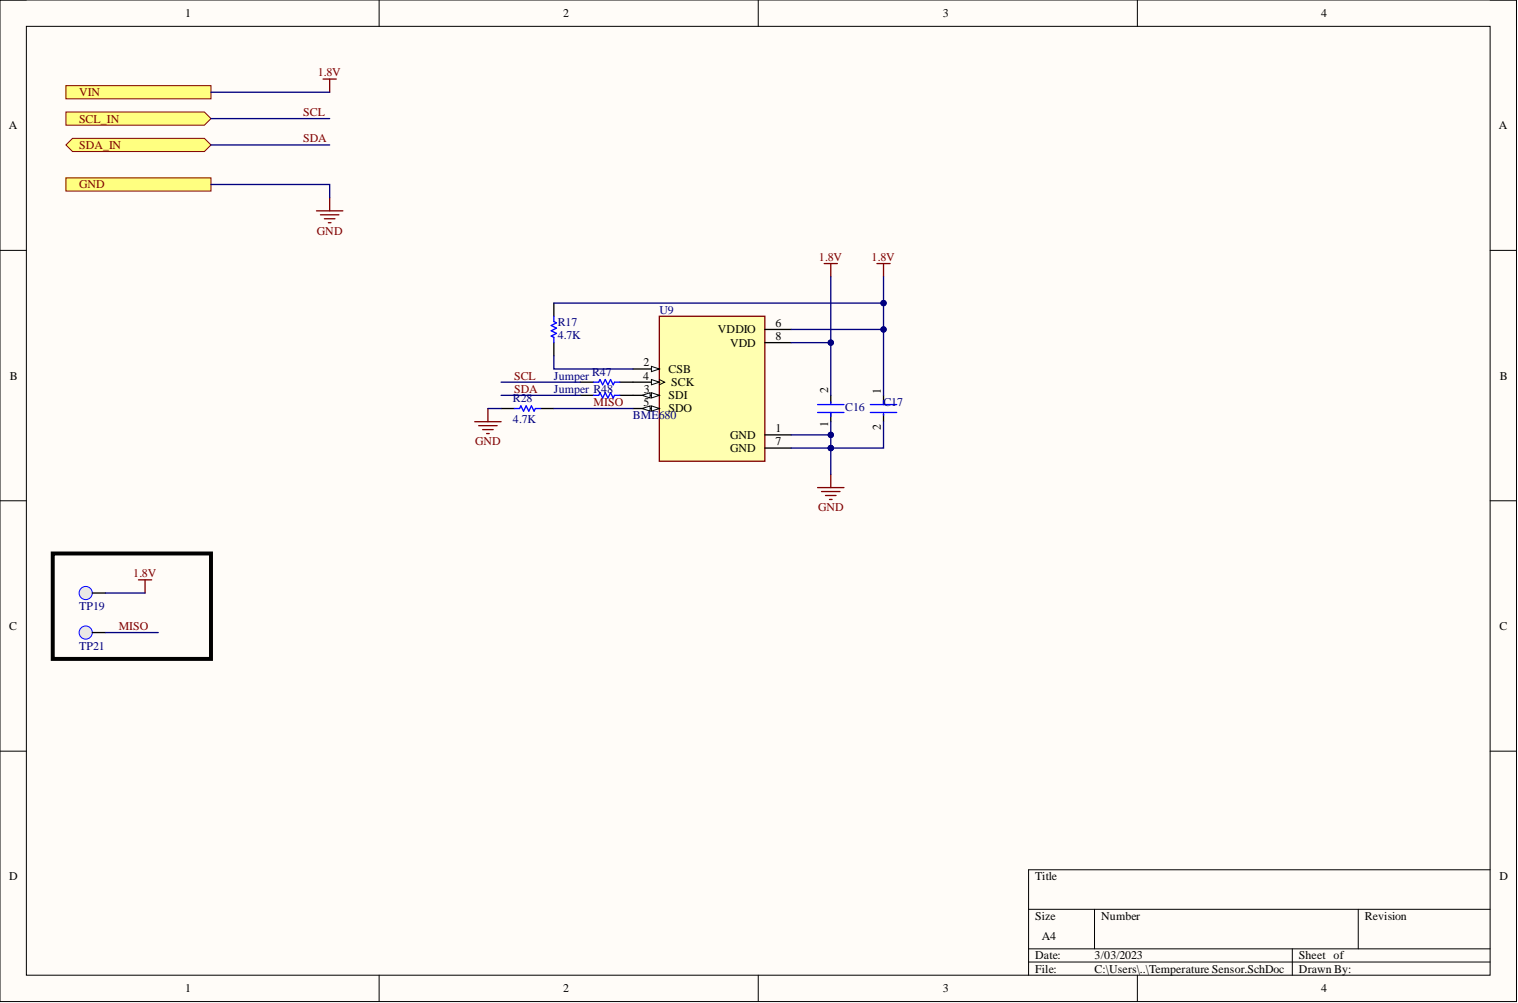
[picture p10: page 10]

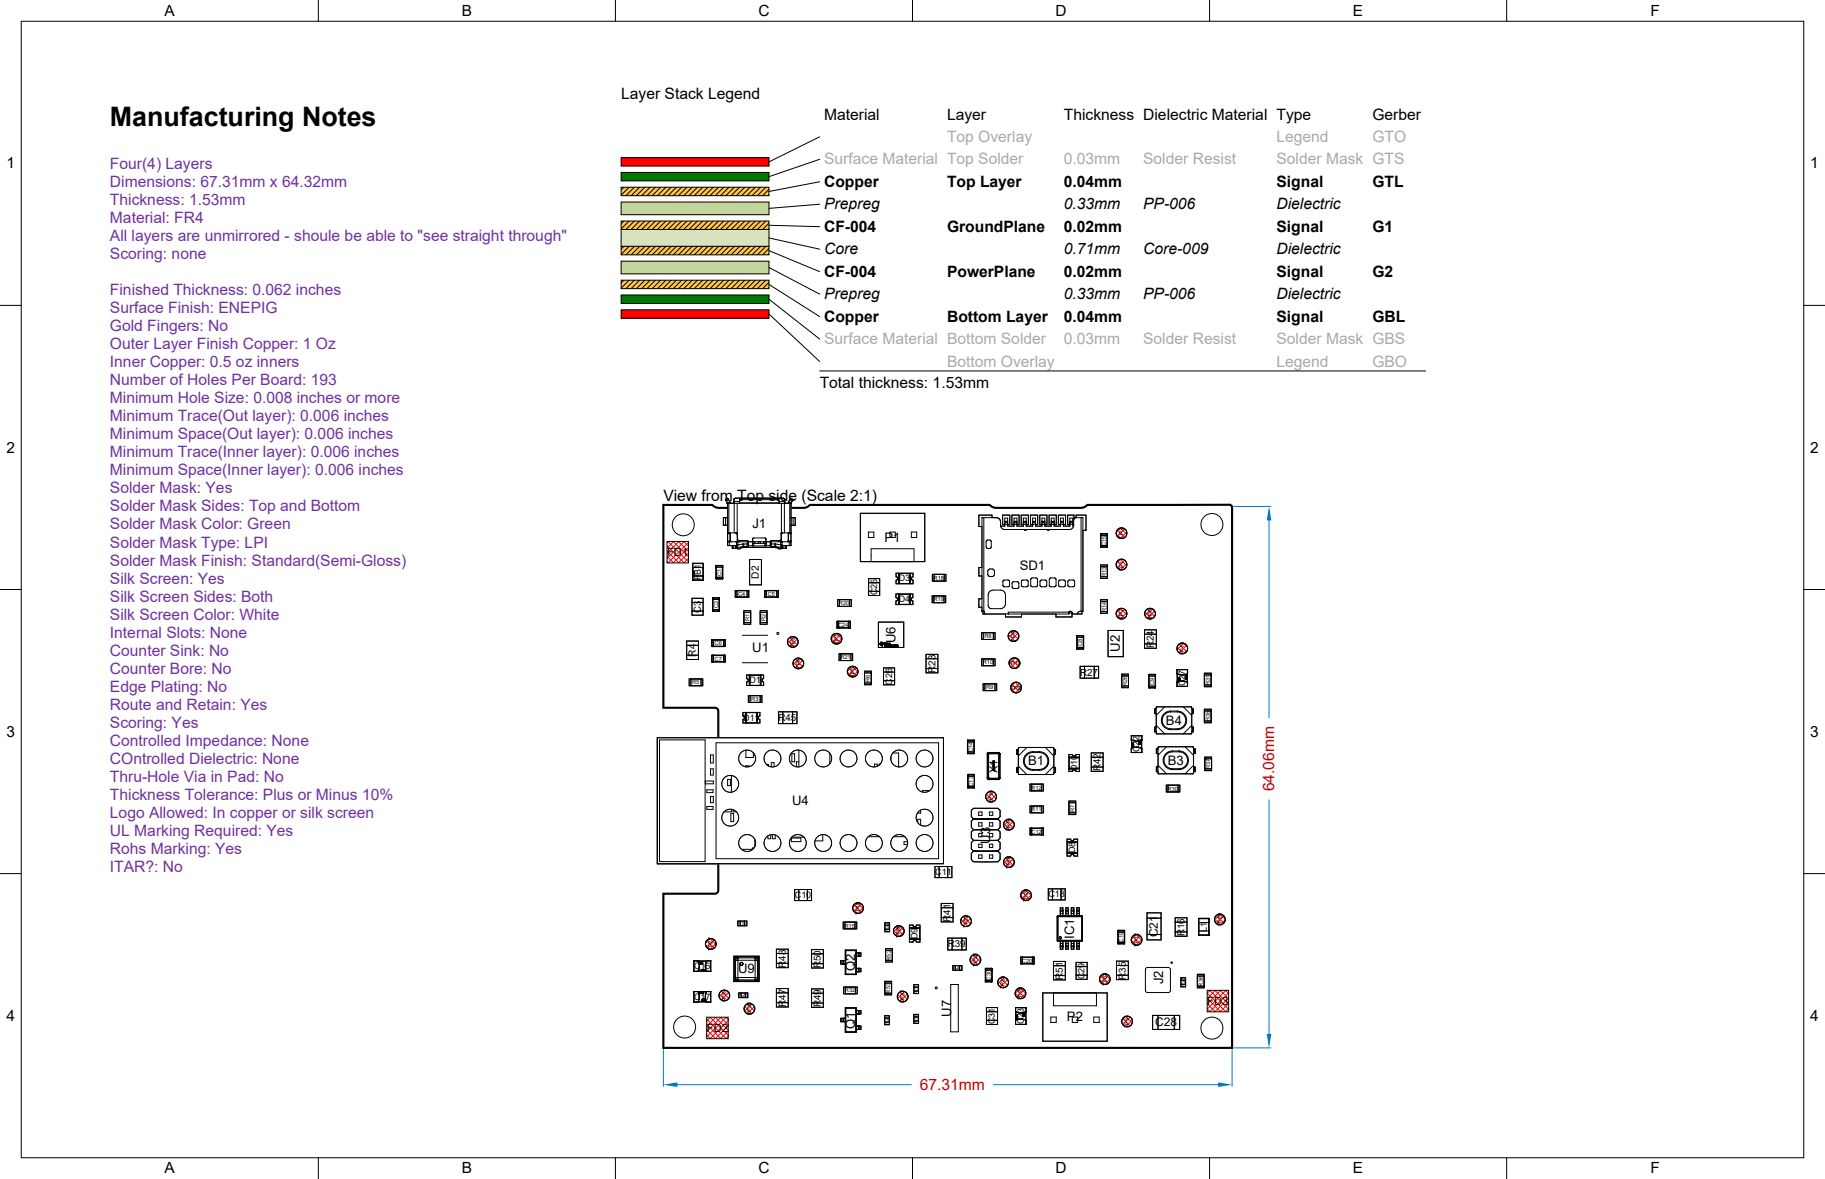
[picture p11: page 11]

Four(4) Layers
Dimensions: 67.31mm x 64.32mm
Thickness: 1.53mm
Material: FR4
All layers are unmirrored - shoule be able to "see straight through"
Scoring: none

Finished Thickness: 0.062 inches
Surface Finish: ENEPIG
Gold Fingers: No
Outer Layer Finish Copper: 1 Oz
Inner Copper: 0.5 oz inners
Number of Holes Per Board: 193
Minimum Hole Size: 0.008 inches or more
Minimum Trace(Out layer): 0.006 inches
Minimum Space(Out layer): 0.006 inches
Minimum Trace(Inner layer): 0.006 inches
Minimum Space(Inner layer): 0.006 inches
Solder Mask: Yes
Solder Mask Sides: Top and Bottom
Solder Mask Color: Green
Solder Mask Type: LPI
Solder Mask Finish: Standard(Semi-Gloss)
Silk Screen: Yes
Silk Screen Sides: Both
Silk Screen Color: White
Internal Slots: None

View from Top side (Scale 2:1)

Counter Sink: No
Counter Bore: No
Edge Plating: No
Route and Retain: Yes
Scoring: Yes
Controlled Impedance: None
COntrolled Dielectric: None

Thru-Hole Via in Pad: No
Thickness Tolerance: Plus or Minus 10%
Logo Allowed: In copper or silk screen
UL Marking Required: Yes
Rohs Marking: Yes
ITAR?: No

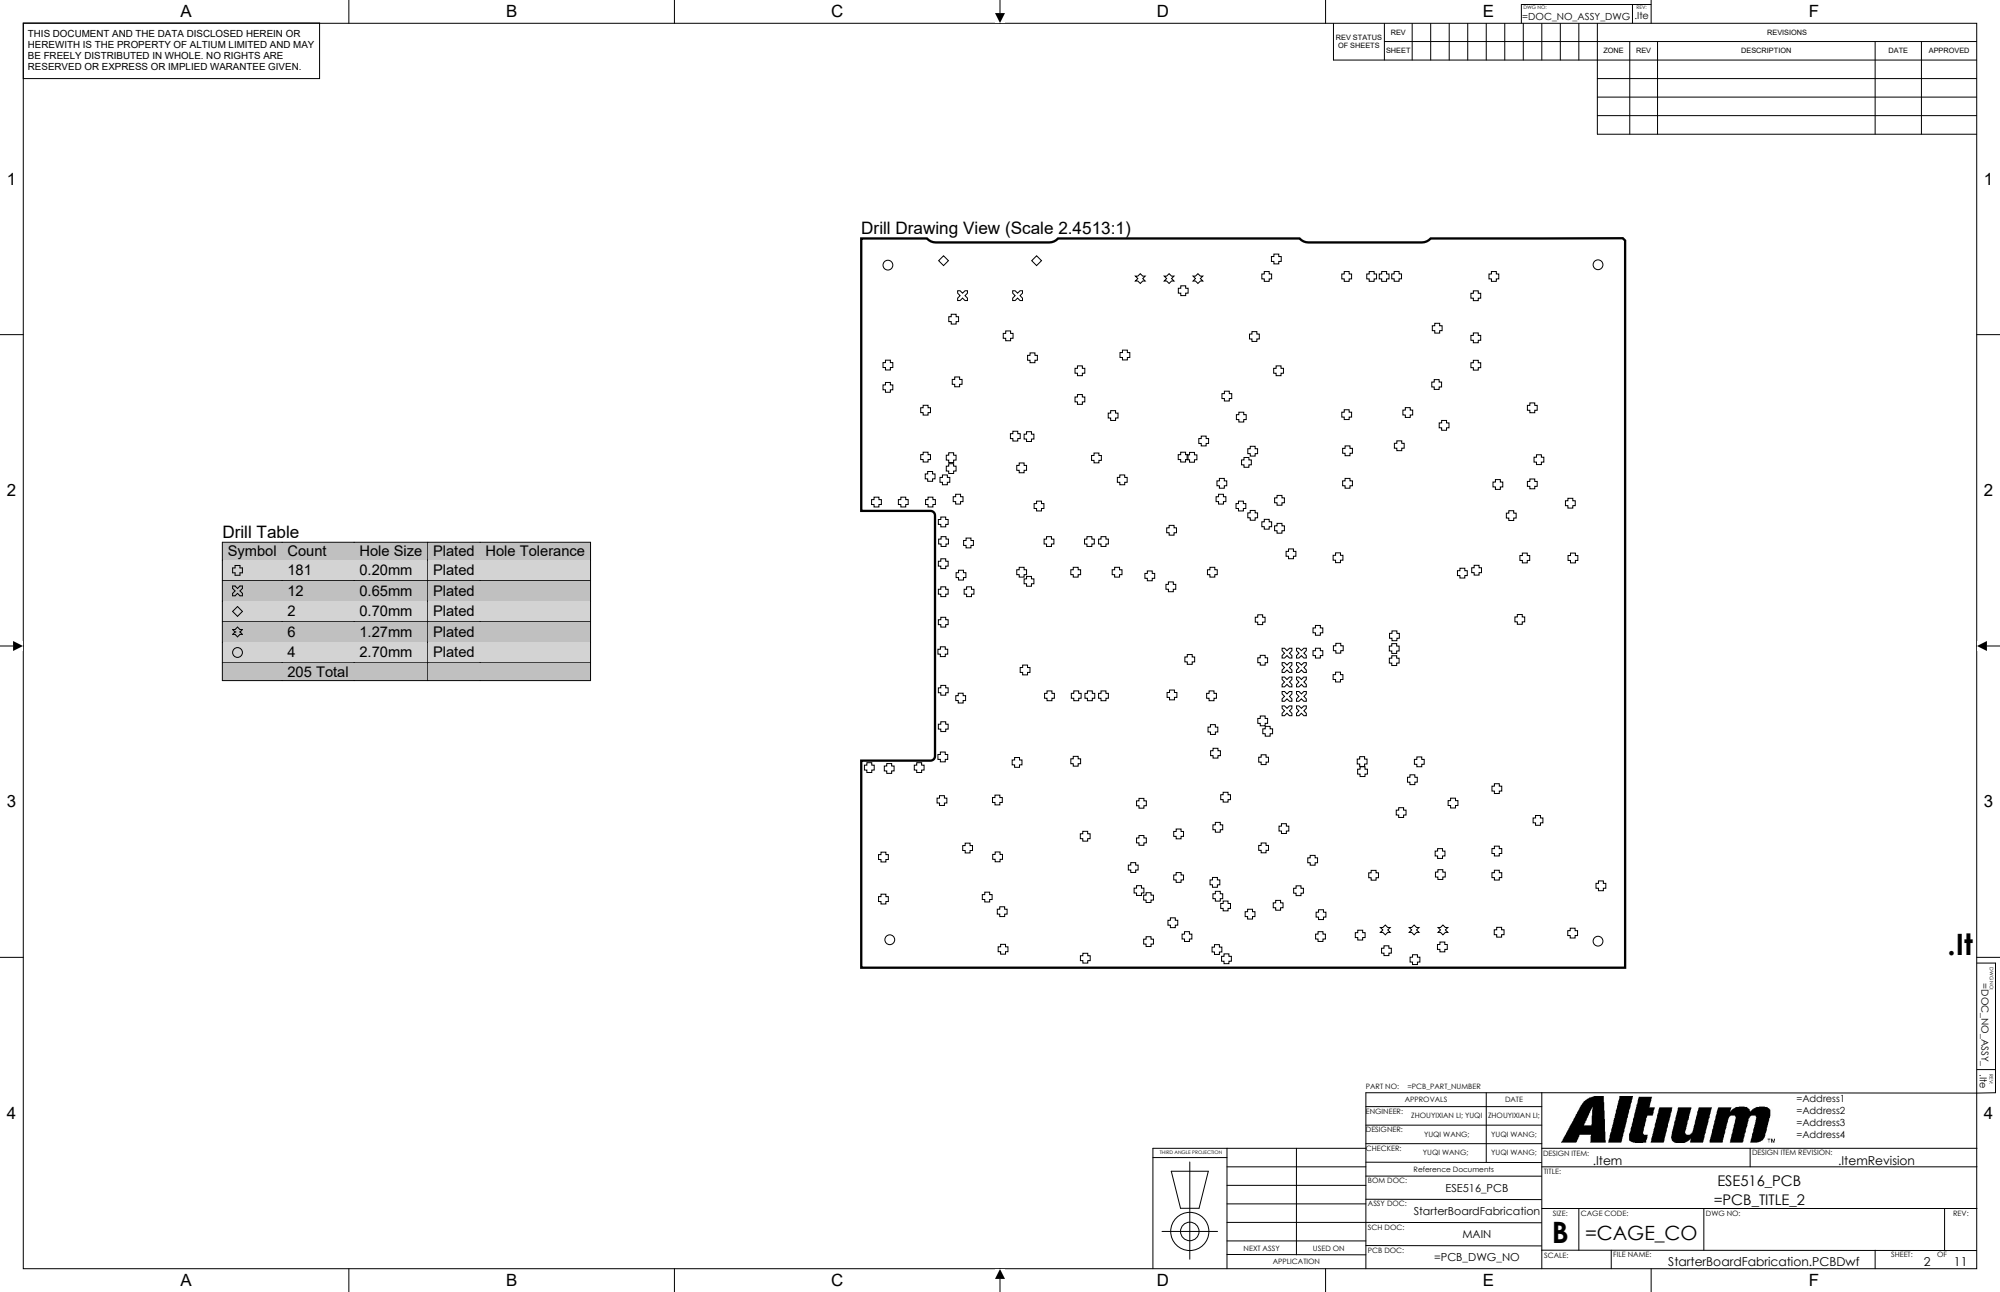
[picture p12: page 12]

HEREWITH IS THE PROPERTY OF ALTIUM LIMITED AND MAY
BE FREELY DISTRIBUTED IN WHOLE. NO RIGHTS ARE
RESERVED OR EXPRESS OR IMPLIED WARANTEE GIVEN.

Drill Drawing View (Scale 2.4513:1)

Symbol | Count | Hole Size | Plated | Hole Tolerance

181 | 0.20mm | Plated
12 | 0.65mm | Plated
2 | 0.70mm | Plated
6 | 1.27mm | Plated
4 | 2.70mm | Plated
205 Total

APPROVALS | DATE

ENGINEER: ZHOUYIXIAN LI; YUQI | ZHOUYIXIAN LI;

DESIGNER: YUQI WANG; | YUQI WANG;

THIRD ANGLE PROJECTION

CHECKER: YUQI WANG; | YUQI WANG;

SCH DOC: MAIN

NEXT ASSY | USED ON


APPROVALS | DATE

ENGINEER: ZHOUYIXIAN LI; YUQI | ZHOUYIXIAN LI;

DESIGNER: YUQI WANG; | YUQI WANG;

THIRD ANGLE PROJECTION

CHECKER: YUQI WANG; | YUQI WANG;


APPROVALS | DATE

ENGINEER: ZHOUYIXIAN LI; YUQI | ZHOUYIXIAN LI;

DESIGNER: YUQI WANG; | YUQI WANG;

THIRD ANGLE PROJECTION

CHECKER: YUQI WANG; | YUQI WANG;


APPROVALS | DATE

ENGINEER: ZHOUYIXIAN LI; YUQI | ZHOUYIXIAN LI;

DESIGNER: YUQI WANG; | YUQI WANG;

THIRD ANGLE PROJECTION

CHECKER: YUQI WANG; | YUQI WANG;


APPROVALS | DATE

ENGINEER: ZHOUYIXIAN LI; YUQI | ZHOUYIXIAN LI;

DESIGNER: YUQI WANG; | YUQI WANG;

THIRD ANGLE PROJECTION

CHECKER: YUQI WANG; | YUQI WANG;


APPROVALS | DATE

ENGINEER: ZHOUYIXIAN LI; YUQI | ZHOUYIXIAN LI;

DESIGNER: YUQI WANG; | YUQI WANG;

THIRD ANGLE PROJECTION

CHECKER: YUQI WANG; | YUQI WANG;


APPROVALS | DATE

ENGINEER: ZHOUYIXIAN LI; YUQI | ZHOUYIXIAN LI;

DESIGNER: YUQI WANG; | YUQI WANG;

THIRD ANGLE PROJECTION

CHECKER: YUQI WANG; | YUQI WANG;


APPROVALS | DATE

ENGINEER: ZHOUYIXIAN LI; YUQI | ZHOUYIXIAN LI;

DESIGNER: YUQI WANG; | YUQI WANG;

THIRD ANGLE PROJECTION

CHECKER: YUQI WANG; | YUQI WANG;


APPROVALS | DATE

ENGINEER: ZHOUYIXIAN LI; YUQI | ZHOUYIXIAN LI;

DESIGNER: YUQI WANG; | YUQI WANG;

THIRD ANGLE PROJECTION

CHECKER: YUQI WANG; | YUQI WANG;


APPROVALS | DATE

ENGINEER: ZHOUYIXIAN LI; YUQI | ZHOUYIXIAN LI;

DESIGNER: YUQI WANG; | YUQI WANG;

THIRD ANGLE PROJECTION

CHECKER: YUQI WANG; | YUQI WANG;


1. THIS ITEM IS ELECTROSTATIC SENSITIVE
AND SHALL BE HANDLED ACCORDINGLY


View from Top side (Scale 5:2)

View from Front side (Scale 1:1)

View from Back side (Scale 1:1)
